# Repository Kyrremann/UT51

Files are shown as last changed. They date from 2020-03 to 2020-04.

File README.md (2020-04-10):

UT51
====

> Hot-swappable nordic 40% Keyboard PCB

The UT51 is a clone of the UT47.2 with an added cloumn for nordic letters. This also enables the use of the traditional
arrow keys.

Keyboard Layout Editor layout: [UT51 Layout](http://www.keyboard-layout-editor.com/#/gists/70864930e7721bd26d8b0cc32576811b)

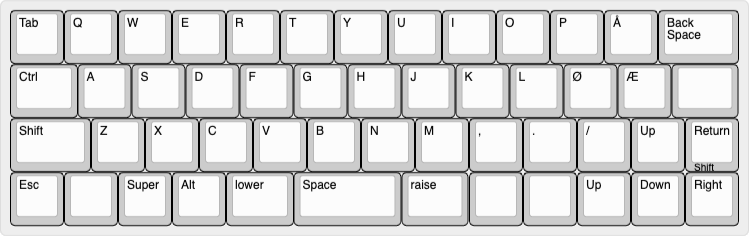
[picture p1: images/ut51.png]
the current keymap


## Diary

### [rev1] - 2020-04-10

About two weeks ago I finally sat down and created the extended UT47.2 board that I wanted to make. It was some work, as
I had messed up the footprint by updating them to a newer version. Also since I had to move all the components for the
micro controller, I had to create most of the traces a new. I've now gotten the product back from production, but
haven't had time to solder it yet.



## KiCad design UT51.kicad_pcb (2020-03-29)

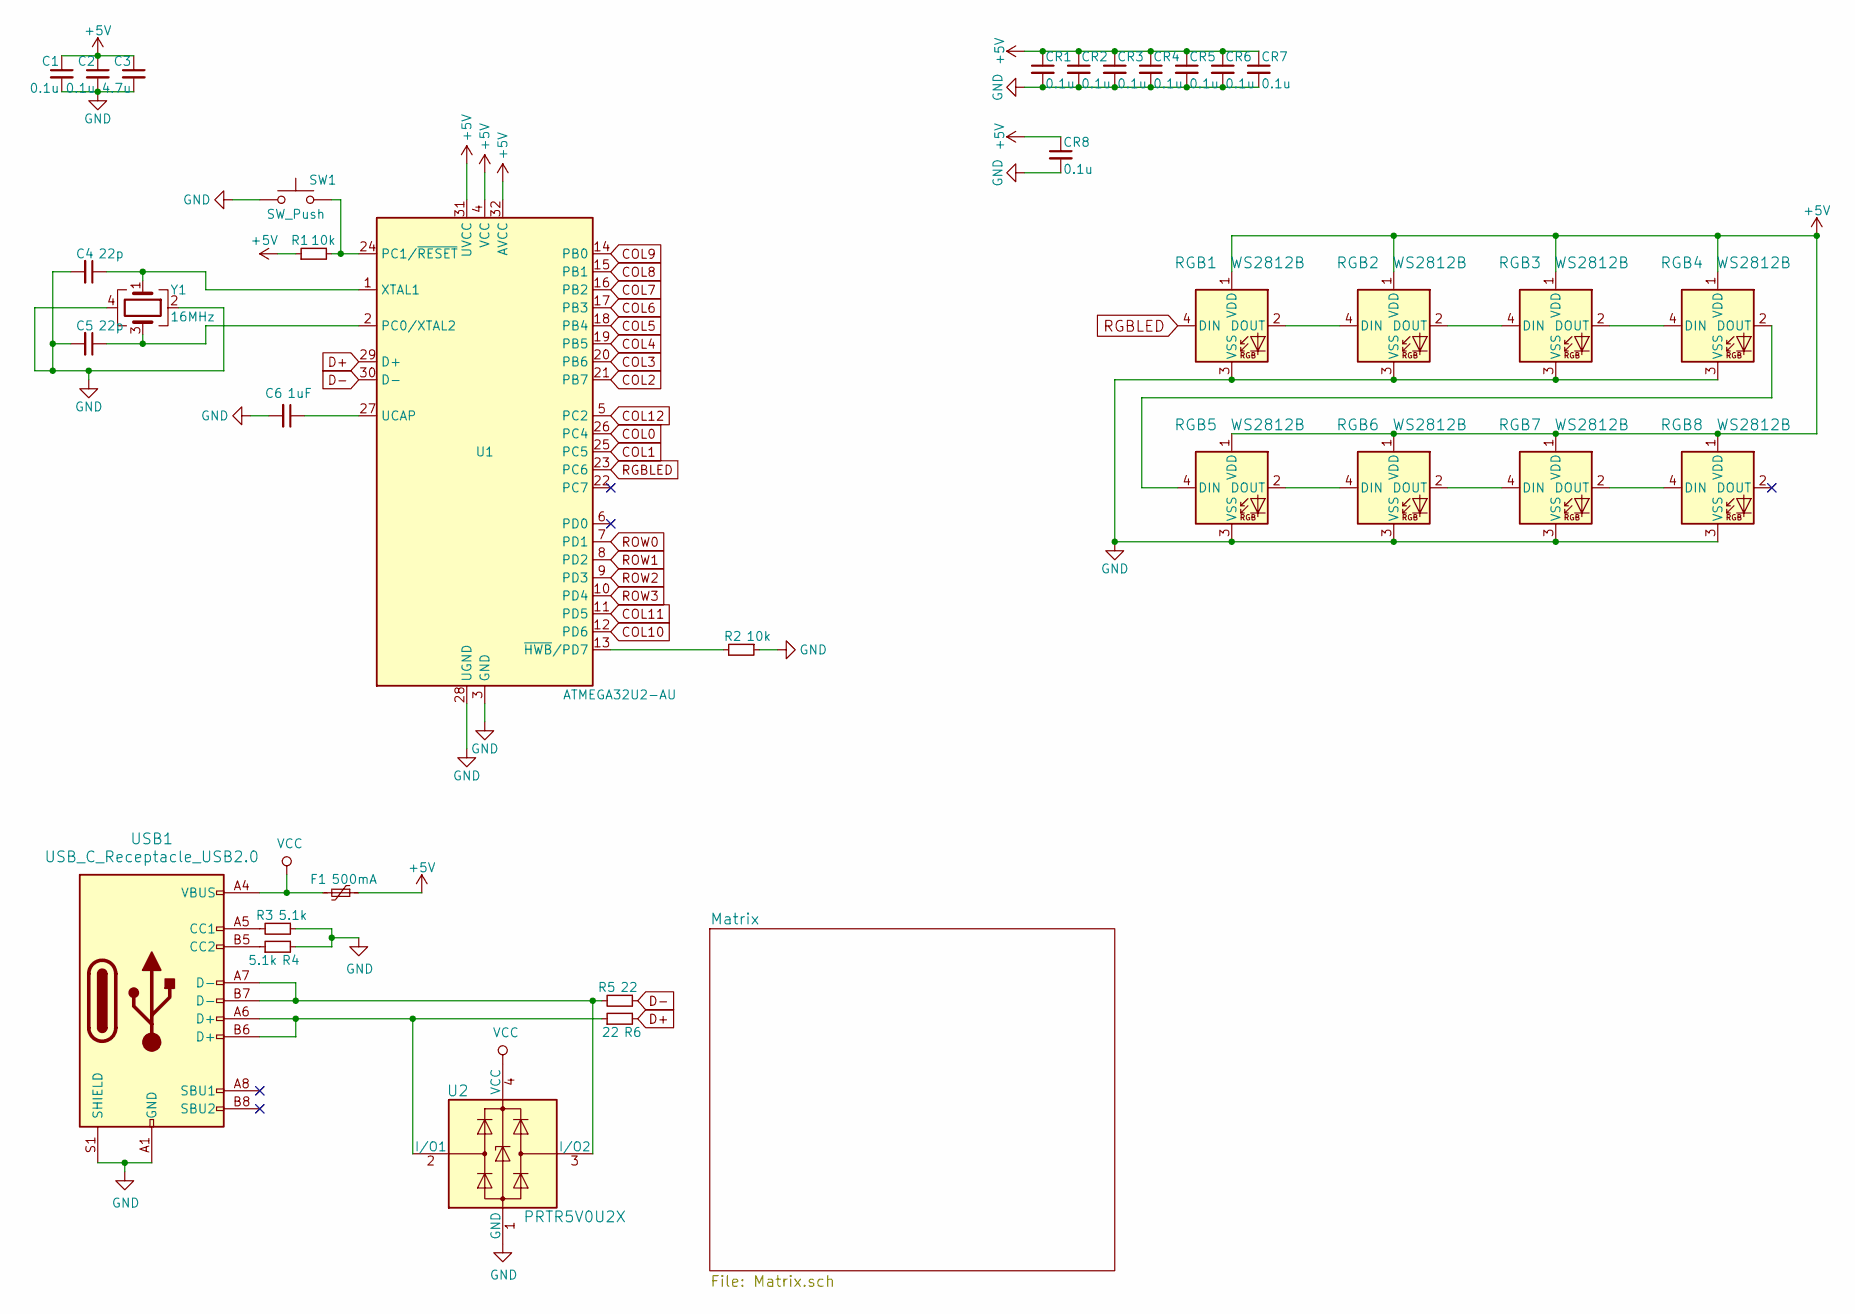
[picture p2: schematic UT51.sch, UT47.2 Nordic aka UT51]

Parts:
C1, C2: 0.1u; C_0603_1608Metric
C3: 4.7u; C_0603_1608Metric
C4, C5: 22p; C_0603_1608Metric
C6: 1uF; C_0603_1608Metric
CR1, CR2, CR3, CR4, CR5, CR6, CR7, CR8: 0.1u; C_0603_1608Metric
F1: 500mA; Fuse_0603_1608Metric
R1, R2: 10k; R_0603_1608Metric
R3, R4: 5.1k; R_0603_1608Metric
R5, R6: 22; R_0603_1608Metric
RGB1, RGB2, RGB3, RGB4, RGB5, RGB6, RGB7, RGB8: WS2812B; LED_WS2812B_PLCC4_5.0x5.0mm_P3.2mm
SW1: SW_Push; SW_SPST_CK_RS282G05A3
U1: ATMEGA32U2-AU; QFN-32-1EP_5x5mm_P0.5mm_EP3.1x3.1mm
U2: PRTR5V0U2X; SOT-143B
USB1: USB_C_Receptacle_USB2.0; USB_C_Receptacle_HRO_TYPE-C-31-M-12
Y1: 16MHz; Crystal_SMD_3225-4Pin_3.2x2.5mm_HandSoldering

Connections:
+5V: C1.1, C2.1, C3.1, CR1.1, CR2.1, CR3.1, CR4.1, CR5.1, CR6.1, CR7.1, CR8.1, F1.1, R1.1, RGB1.1 (VDD), RGB2.1 (VDD), RGB3.1 (VDD), RGB4.1 (VDD), RGB5.1 (VDD), RGB6.1 (VDD), RGB7.1 (VDD), RGB8.1 (VDD), U1.4 (VCC), U1.31 (UVCC), U1.32 (AVCC)
COL0: U1.26 (PC4); also elsewhere on the board
COL1: U1.25 (PC5); also elsewhere on the board
COL2: U1.21 (PB7); also elsewhere on the board
COL3: U1.20 (PB6); also elsewhere on the board
COL4: U1.19 (PB5); also elsewhere on the board
COL5: U1.18 (PB4); also elsewhere on the board
COL6: U1.17 (PB3); also elsewhere on the board
COL7: U1.16 (PB2); also elsewhere on the board
COL8: U1.15 (PB1); also elsewhere on the board
COL9: U1.14 (PB0); also elsewhere on the board
COL10: U1.12 (PD6); also elsewhere on the board
COL11: U1.11 (PD5); also elsewhere on the board
COL12: U1.5 (PC2); also elsewhere on the board
D+: R6.2, U1.29 (D+)
D-: R5.1, U1.30 (D-)
GND: C1.2, C2.2, C3.2, C4.2, C5.2, C6.2, CR1.2, CR2.2, CR3.2, CR4.2, CR5.2, CR6.2, CR7.2, CR8.2, R2.1, R3.1, R4.2, RGB1.3 (VSS), RGB2.3 (VSS), RGB3.3 (VSS), RGB4.3 (VSS), RGB5.3 (VSS), RGB6.3 (VSS), RGB7.3 (VSS), RGB8.3 (VSS), SW1.1, U1.3 (GND), U1.28 (UGND), U1.33 (GND), U2.1 (GND), USB1.A1 (GND), USB1.A12 (GND), USB1.B1 (GND), USB1.B12 (GND), USB1.S1 (SHIELD), Y1.2, Y1.4
unnamed: C4.1, U1.1 (XTAL1), Y1.1
unnamed: C5.1, U1.2 (PC0/XTAL2), Y1.3
unnamed: C6.1, U1.27 (UCAP)
unnamed: R1.2, SW1.2, U1.24 (PC1/~RESET)
unnamed: R2.2, U1.13 (~HWB~/PD7)
unnamed: R3.2, USB1.A5 (CC1)
unnamed: R4.1, USB1.B5 (CC2)
unnamed: R5.2, U2.3 (I/O2), USB1.A7 (D-), USB1.B7 (D-)
unnamed: R6.1, U2.2 (I/O1), USB1.A6 (D+), USB1.B6 (D+)
unnamed: RGB1.2 (DOUT), RGB2.4 (DIN)
unnamed: RGB2.2 (DOUT), RGB3.4 (DIN)
unnamed: RGB3.2 (DOUT), RGB4.4 (DIN)
unnamed: RGB4.2 (DOUT), RGB5.4 (DIN)
unnamed: RGB5.2 (DOUT), RGB6.4 (DIN)
unnamed: RGB6.2 (DOUT), RGB7.4 (DIN)
unnamed: RGB7.2 (DOUT), RGB8.4 (DIN)
RGBLED: RGB1.4 (DIN), U1.23 (PC6)
ROW0: U1.7 (PD1); also elsewhere on the board
ROW1: U1.8 (PD2); also elsewhere on the board
ROW2: U1.9 (PD3); also elsewhere on the board
ROW3: U1.10 (PD4); also elsewhere on the board
VCC: F1.2, U2.4 (VCC), USB1.A4 (VBUS), USB1.A9 (VBUS), USB1.B4 (VBUS), USB1.B9 (VBUS)

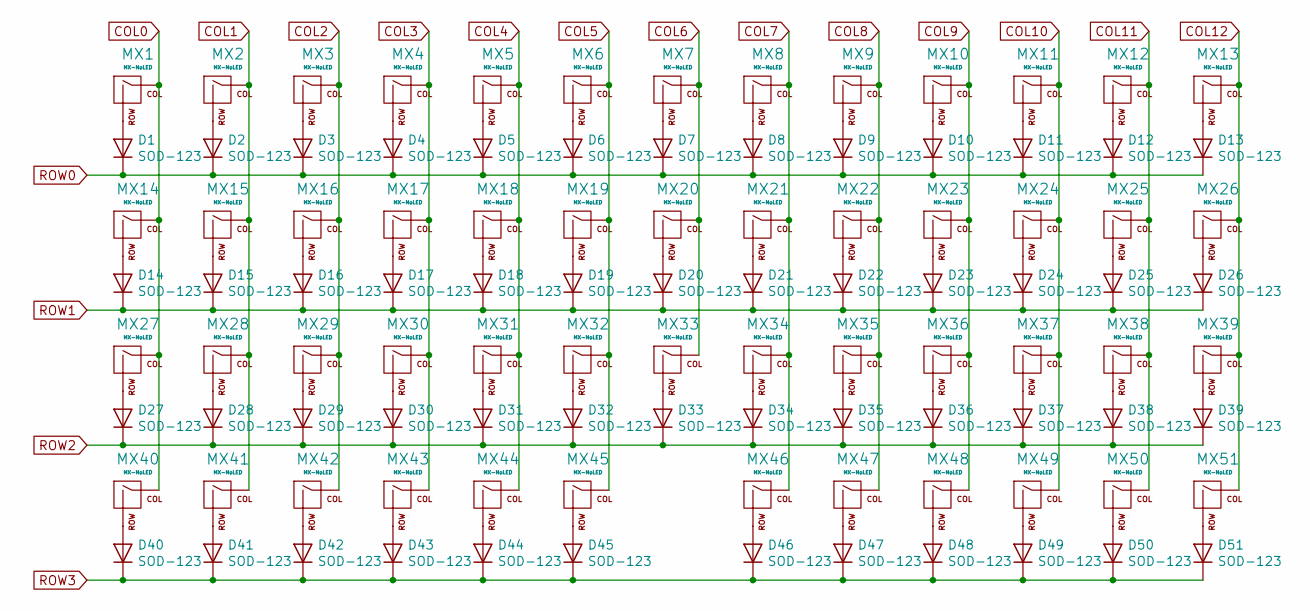
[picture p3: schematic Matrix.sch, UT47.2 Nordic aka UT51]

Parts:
D1, D2, D3, D4, D5, D6, D7, D8, D9, D10, D11, D12, D13, D14, D15, D16, D17, D18, D19, D20, D21, D22, D23, D24, D25, D26, D27, D28, D29, D30, D31, D32, D33, D34, D35, D36, D37, D38, D39, D40, D41, D42, D43, D44, D45, D46, D47, D48, D49, D50, D51: SOD-123; D_SOD-123
MX1, MX2, MX3, MX4, MX5, MX6, MX7, MX8, MX9, MX10, MX11, MX12, MX13, MX14, MX15, MX16, MX17, MX18, MX19, MX20, MX21, MX22, MX23, MX24, MX25, MX26, MX27, MX28, MX29, MX30, MX31, MX32, MX33, MX34, MX35, MX36, MX37, MX38, MX39, MX40, MX41, MX42, MX43, MX44, MX45, MX46, MX47, MX48, MX49, MX50, MX51: MX-NoLED; Kailh_socket_MX

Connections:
COL0: MX1.1 (COL), MX14.1 (COL), MX27.1 (COL), MX40.1 (COL); also elsewhere on the board
COL1: MX2.1 (COL), MX15.1 (COL), MX28.1 (COL), MX41.1 (COL); also elsewhere on the board
COL2: MX3.1 (COL), MX16.1 (COL), MX29.1 (COL), MX42.1 (COL); also elsewhere on the board
COL3: MX4.1 (COL), MX17.1 (COL), MX30.1 (COL), MX43.1 (COL); also elsewhere on the board
COL4: MX5.1 (COL), MX18.1 (COL), MX31.1 (COL), MX44.1 (COL); also elsewhere on the board
COL5: MX6.1 (COL), MX19.1 (COL), MX32.1 (COL), MX45.1 (COL); also elsewhere on the board
COL6: MX7.1 (COL), MX20.1 (COL), MX33.1 (COL); also elsewhere on the board
COL7: MX8.1 (COL), MX21.1 (COL), MX34.1 (COL), MX46.1 (COL); also elsewhere on the board
COL8: MX9.1 (COL), MX22.1 (COL), MX35.1 (COL), MX47.1 (COL); also elsewhere on the board
COL9: MX10.1 (COL), MX23.1 (COL), MX36.1 (COL), MX48.1 (COL); also elsewhere on the board
COL10: MX11.1 (COL), MX24.1 (COL), MX37.1 (COL), MX49.1 (COL); also elsewhere on the board
COL11: MX12.1 (COL), MX25.1 (COL), MX38.1 (COL), MX50.1 (COL); also elsewhere on the board
COL12: MX13.1 (COL), MX26.1 (COL), MX39.1 (COL), MX51.1 (COL); also elsewhere on the board
unnamed: D1.2 (A), MX1.2 (ROW)
unnamed: D2.2 (A), MX2.2 (ROW)
unnamed: D3.2 (A), MX3.2 (ROW)
unnamed: D4.2 (A), MX4.2 (ROW)
unnamed: D5.2 (A), MX5.2 (ROW)
unnamed: D6.2 (A), MX6.2 (ROW)
unnamed: D7.2 (A), MX7.2 (ROW)
unnamed: D8.2 (A), MX8.2 (ROW)
unnamed: D9.2 (A), MX9.2 (ROW)
unnamed: D10.2 (A), MX10.2 (ROW)
unnamed: D11.2 (A), MX11.2 (ROW)
unnamed: D12.2 (A), MX12.2 (ROW)
unnamed: D13.2 (A), MX13.2 (ROW)
unnamed: D14.2 (A), MX14.2 (ROW)
unnamed: D15.2 (A), MX15.2 (ROW)
unnamed: D16.2 (A), MX16.2 (ROW)
unnamed: D17.2 (A), MX17.2 (ROW)
unnamed: D18.2 (A), MX18.2 (ROW)
unnamed: D19.2 (A), MX19.2 (ROW)
unnamed: D20.2 (A), MX20.2 (ROW)
unnamed: D21.2 (A), MX21.2 (ROW)
unnamed: D22.2 (A), MX22.2 (ROW)
unnamed: D23.2 (A), MX23.2 (ROW)
unnamed: D24.2 (A), MX24.2 (ROW)
unnamed: D25.2 (A), MX25.2 (ROW)
unnamed: D26.2 (A), MX26.2 (ROW)
unnamed: D27.2 (A), MX27.2 (ROW)
unnamed: D28.2 (A), MX28.2 (ROW)
unnamed: D29.2 (A), MX29.2 (ROW)
unnamed: D30.2 (A), MX30.2 (ROW)
unnamed: D31.2 (A), MX31.2 (ROW)
unnamed: D32.2 (A), MX32.2 (ROW)
unnamed: D33.2 (A), MX33.2 (ROW)
unnamed: D34.2 (A), MX34.2 (ROW)
unnamed: D35.2 (A), MX35.2 (ROW)
unnamed: D36.2 (A), MX36.2 (ROW)
unnamed: D37.2 (A), MX37.2 (ROW)
unnamed: D38.2 (A), MX38.2 (ROW)
unnamed: D39.2 (A), MX39.2 (ROW)
unnamed: D40.2 (A), MX40.2 (ROW)
unnamed: D41.2 (A), MX41.2 (ROW)
unnamed: D42.2 (A), MX42.2 (ROW)
unnamed: D43.2 (A), MX43.2 (ROW)
unnamed: D44.2 (A), MX44.2 (ROW)
unnamed: D45.2 (A), MX45.2 (ROW)
unnamed: D46.2 (A), MX46.2 (ROW)
unnamed: D47.2 (A), MX47.2 (ROW)
unnamed: D48.2 (A), MX48.2 (ROW)
unnamed: D49.2 (A), MX49.2 (ROW)
unnamed: D50.2 (A), MX50.2 (ROW)
unnamed: D51.2 (A), MX51.2 (ROW)
ROW0: D1.1 (K), D2.1 (K), D3.1 (K), D4.1 (K), D5.1 (K), D6.1 (K), D7.1 (K), D8.1 (K), D9.1 (K), D10.1 (K), D11.1 (K), D12.1 (K), D13.1 (K); also elsewhere on the board
ROW1: D14.1 (K), D15.1 (K), D16.1 (K), D17.1 (K), D18.1 (K), D19.1 (K), D20.1 (K), D21.1 (K), D22.1 (K), D23.1 (K), D24.1 (K), D25.1 (K), D26.1 (K); also elsewhere on the board
ROW2: D27.1 (K), D28.1 (K), D29.1 (K), D30.1 (K), D31.1 (K), D32.1 (K), D33.1 (K), D34.1 (K), D35.1 (K), D36.1 (K), D37.1 (K), D38.1 (K), D39.1 (K); also elsewhere on the board
ROW3: D40.1 (K), D41.1 (K), D42.1 (K), D43.1 (K), D44.1 (K), D45.1 (K), D46.1 (K), D47.1 (K), D48.1 (K), D49.1 (K), D50.1 (K), D51.1 (K); also elsewhere on the board

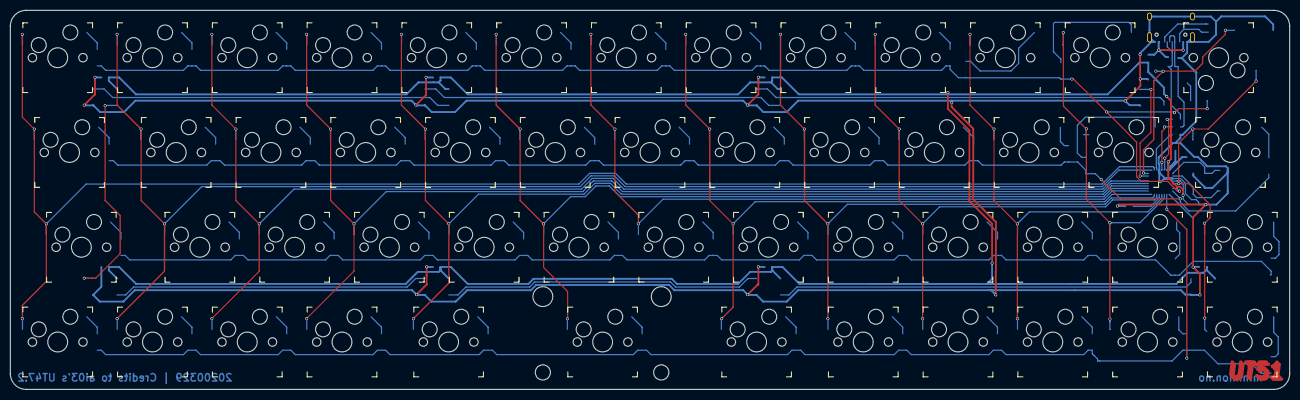
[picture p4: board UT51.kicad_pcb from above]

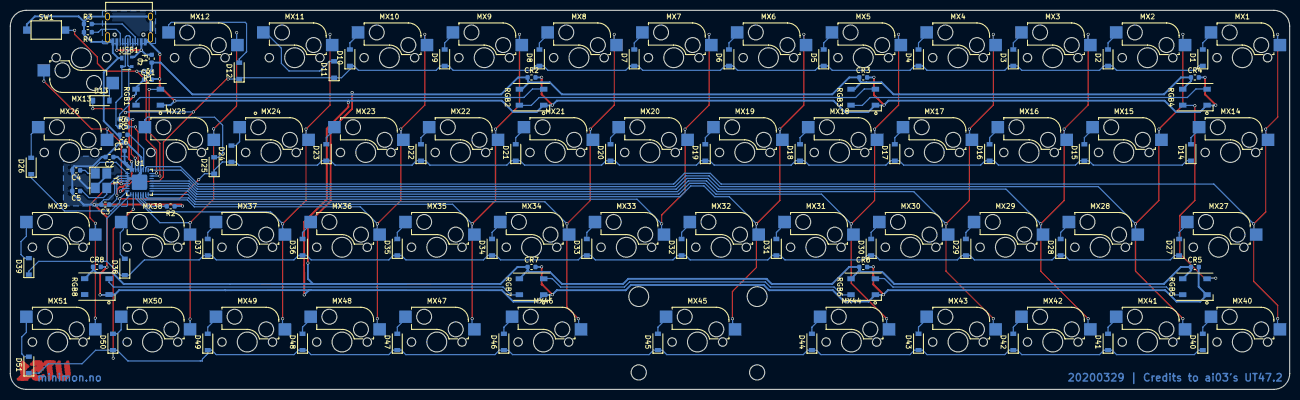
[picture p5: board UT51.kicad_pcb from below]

Board: 2 copper layers, 257.2 x 76.2 mm, 136 parts (85 on the bottom side), 90 nets.

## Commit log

2020-02-15 Init commit
    Updated the schematics. Next up is PCB
    [Matrix.sch, UT51.kicad_pcb, UT51.sch]
2020-03-04 Added the new coloumn
    Added all the needed components, just need to fix the PCB.
    [Matrix.sch, UT51.kicad_pcb, UT51.sch]
2020-03-29 Finished first revision
    Should be okay to order now
    [Matrix.sch, UT51.kicad_pcb, UT51.sch]
2020-04-10 Rev1 sent to production
    [UT51-B_Cu.gbl, UT51-B_Mask.gbs, UT51-B_Paste.gbp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]

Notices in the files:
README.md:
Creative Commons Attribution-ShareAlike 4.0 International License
